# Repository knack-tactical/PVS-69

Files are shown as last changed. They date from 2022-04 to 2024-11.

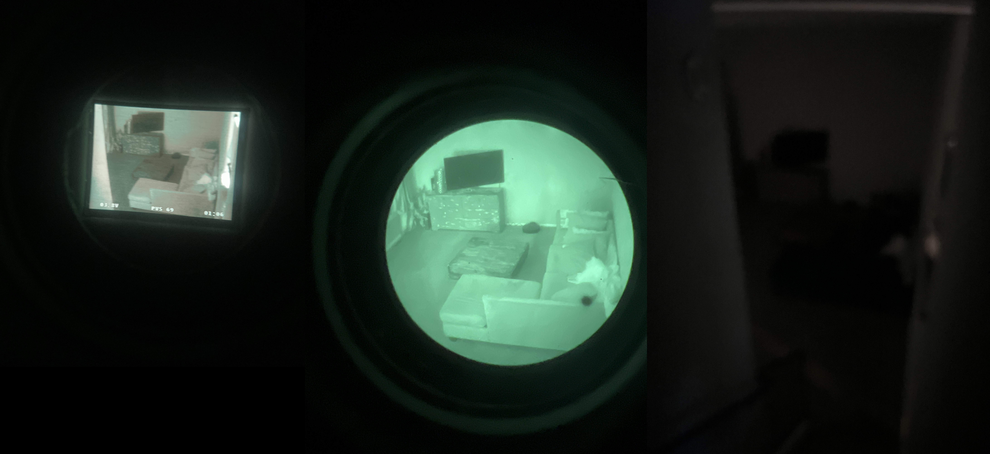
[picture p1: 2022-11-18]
.faq_pictures/cs_mount_digital.jpg

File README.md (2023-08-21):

# PVS-69

__Disclaimer__: This project is experimental, still in development, and is recommended for experienced tinkerers and solderers. Don't let that disuade you, but know that documentation, methods, and peocedures are not production ready.

[Frequently Asked Questions can be found here.](https://github.com/knack-69/PVS-69/wiki/Frequently-Asked-Questions)

### What is it?
PVS-69 is a FOSSCAD Night Vision Device (NVD). 
It uses a fpv drone camera and a small screen, rather than a IIT tube, and is designed to be mounted to a combat helmet.

### Why is it useful?
The current suggested components cost ~$500, about 10x less than the industry standard phosphor tube-based night vision.

### What is the current version?

The current version of the PVS-69 is the [Gen3 FOXTROT](https://github.com/knack-69/PVS-69/tree/main/Gen3%20FOXTROT). Housings for both V760 and V780 displays are available. The Gen3 FOXTROT also comes with a CS Mount Lens Adapter Assembly ([see here for writeup on lenses](https://github.com/knack-69/PVS-69/wiki/Current-Lens-Comparison)), which is interchangable with the NE3 Stock Lens Cap.

## Table of Contents

[PVS-69/Gen3 FOXTROT](https://github.com/knack-69/PVS-69/tree/main/Gen3%20FOXTROT) is the current version of the PVS-69 that is compatible with the V760A family of displays.

[PVS-69/Wiring Diagrams](https://github.com/knack-69/PVS-69/tree/main/Gen3%20FOXTROT/Wiring%20Diagrams) contains the current wiring diagrams for the current version of the PVS-69.

[PVS-69/_Older Versions/__Archive](https://github.com/knack-tactical/PVS-69/tree/main/Older%20Versions/__Archive) contains all the older versions of the PVS-69.

[PVS-69/Gen4 ALPHA](https://github.com/knack-69/PVS-69/tree/main/Gen4%20ALPHA) is an analog/'digital IIT' NVG housing, and is still in closed beta.

[PVS-69/_Olders Versions/__Archive/VPNVG](https://github.com/knack-69/PVS-69/tree/main/_Older%20Versions/__Archive/VPNVG)  is the PVS-69 Gen1 pano version using the adafruit displays. The VBNVG was a binocular version which was made in tandem with the VPNVG.

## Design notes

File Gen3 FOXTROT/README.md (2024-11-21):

# PVS-69 Gen3 FOXTROT

## Changes from ECHO to FOXTROT

The PVS-69 Gen3 FOXTROT is currently in beta testing. Take that as a word of caution. Please read all the changes.

(Beta testing) FOXTROT changes:
Expanded inner bore for use with V780 display.

Condensed overall pod length but moved the display bore deeper in the pod.

Opened up the area where the cam connector goes to accommodate more cams.

Added area for the OSD cable to come out the front.

Added CS mount quick change system. Still usable with the classic caps (Called 'NE3 Stock Sensor Cap' in .step)

Added holes to screw the sensor down for the lens quick change system.

New Gen4 Bridge (front load) does not require brass tubing however, should be able to accept it.

Both bridges now support the use of M3 bolts to individually adjust pod tightness.

Both bridges have a push-to overcome-latch to stow the tubes to the side.

Battery bridge has been slimmed down slightly more to accomadate narrower IPD, might need some tweaking.

As for the CS Mount Lens deal, basically, you can either use the NE3 Stock Lens (or XENOCAM Varifocus lens) *or* you can use the CS Mount Lens with the 'CS Mount Lens Assembly' (in the .step). [See this wiki page for links to the different lenses.](https://github.com/knack-69/PVS-69/wiki/Current-Lens-Comparison). If you aren't planning on using the CS mount lens, don't print the 'CS Mount Lens Assembly' items. ezpz

## Bill of Materials 

### This design requires the following printed components: 

1x [Dovetail](https://github.com/knack-69/PVS-69/blob/main/Gen3%20FOXTROT/STL/FOXTROT%20Gen4%20Dovetail.stl)

1x Bridge Body. In this design, there are 3 Bridge options:
1. Gen3 Bridge is the same bridge as older versions, with an internal battery compartment.
2. [Gen4 Bridge](https://github.com/knack-69/PVS-69/blob/main/Gen3%20FOXTROT/STL/FOXTROT%20Gen4%20Bridge%20Body.stl) is a newer, sleeker bridge that does *not* have an internal battery compartment. This version allows the user to more easily build the internals of the bridge and then load it into the front.

1x Bridge Backplate, which will depend on the Bridge body you choose

2x Sensor Caps - This will depend on whether you're using stock, CS Mount, M16, or some other lenses.

2x [TIPs (Tube Interface Pieces)](https://github.com/knack-69/PVS-69/blob/main/Gen3%20FOXTROT/STL/FOXTROT%20Brassless%20TIP.stl)

2x Ambi Tubes

- If you're using V760 Displays, [click here](https://github.com/knack-69/PVS-69/tree/main/Gen3%20FOXTROT/STL/Files%20for%20V760%20Displays)
- If you're using V780 Displays, [click here](https://github.com/knack-69/PVS-69/tree/main/Gen3%20FOXTROT/STL/Files%20for%20V780%20Displays)

1x Battery Cap (Only needed if using Gen3 Bridge)

2x Collars

- see 'Ambi Tubes' above

### This design requires the following physical components: (*This list is still under development*)

#### Hardware parts kits can be found at [vonscherfarms.com](https://vonscherfarms.com/).

---

#### Gen3 Bridge (Internal and External Battery)

1x [3-Position Rotary Switch](https://amzn.to/3TspGUS)

11x [M5x8 Bolts](https://amzn.to/3EyraZz)

11x [M5x5.8 Heat-set Inserts](https://amzn.to/3E0fzRt)

2x [RunCam Night Eagle 3](https://amzn.to/3Epdyhh)

2x V760A-5 or V760A-3 displays. These can be found on Ebay or AliExpress, expect a month for shipping.

1x [5.5x2.1mm DC Female Jack](https://amzn.to/3KLofNA)

1x [AA Spring Terminal](https://amzn.to/3EysOdH)

1x [Buck Converter](https://amzn.to/3KSzHHf) (if not using a [5V USB Power Bank](https://a.co/d/cTgl3xK), see [this writeup](https://github.com/knack-69/PVS-69/blob/main/Choosing%20the%20Right%20Battery%20Setup%20for%20My%20PVS-69.pdf) for more information)

2x [10x2mm Nitrile O-ring](https://amzn.to/37mEOko)

2x [13x3mm Nitrile O-ring](https://amzn.to/3KRAmsA)

5x [22x2mm Nitrile O-ring](https://amzn.to/3rrIp7N) (you can buy a [multipack](https://www.amazon.com/gp/product/B092MDGM110) that has all three sizes, thickness is not terribly important)

Approximately 24" of [20-24 AWG wire](https://amzn.to/3EoQ5yn)

3” section of 16AWG single strand wire (for internal battery positive connection)

---

#### Gen4 Bridge (External Battery Only)  

1x [Buck Converter](https://amzn.to/3KSzHHf) (if not using a 5V USB Power Bank, like [this one](https://a.co/d/cTgl3xK), see [this writeup](https://github.com/knack-69/PVS-69/blob/main/Choosing%20the%20Right%20Battery%20Setup%20for%20My%20PVS-69.pdf) for more information)

8x [M5x8mm Bolts](https://amzn.to/3EyraZz)

8x [M5x5.8mm Threaded Inserts](https://amzn.to/3E0fzRt)

6x [M3x45mm Bolts](https://a.co/d/08iu33J)

6x M3 Nuts (nylock would be better, but standard is fine)

1x [Push Button](https://amzn.to/3Txgdvg) or [3-Position Rotary Switch](https://amzn.to/3TspGUS)

4x [Brass Washers](https://amzn.to/3WSWOI2)

1x [5.5x2.1mm DC Female Jack](https://amzn.to/3KLofNA)

2x [12mm Nitrile O-ring](https://amzn.to/3fV4qcD)

3X [22mm Nitrile O-ring](https://amzn.to/3V5NT4D)

2x [35mm Nitrile O-ring](https://amzn.to/3fVgjz8)

Approximately 24" of [20-24 AWG wire](https://amzn.to/3EoQ5yn)

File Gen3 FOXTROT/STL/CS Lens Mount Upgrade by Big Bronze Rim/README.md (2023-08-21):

These files are an upgrade to the CS Lens Mount files for the Gen3 FOXTROT.
 - CS_Focus_Insert
    - This slots into the camera hole of the Gen3 FOXTROT Ambi Tube.
 - CS_Ribbed_Spacer
    - This is functionally the same as the CS_Lens_Mount_Adapter.stl, but is ribbed for aesthetics.
 - CS_Tapered_Retaining_Collar
    - This uses a screw to affix it to the lens so that it rotates when the lens body is spun to allow it to engage against the CS_Focus_Insert.
    - It uses the CS_Lens_Mount_Retainer, which just needs to be loosened to change the focus.
 - PVS14_Focus_Ring_Outer
    - This acts the same as the CS_Lens_Mount_Shroud.stl, but is a bit larger.

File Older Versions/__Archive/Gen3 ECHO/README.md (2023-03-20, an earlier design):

# PVS-69 Gen3 ECHO

## Changes from DELTA to ECHO

The PVS-69 ECHO has a few changes in functionality, size, and printabilty.

ECHO has improved water resistance with the addition of a retaining collar for the displays.

The bridge has been slimmed down and optimized for printing, now called Gen4 Bridge. The Gen4 Bridge has two variations, front-loading and back-loading. The back-loading version should help with wiring the internals of the bridge.

The internal battery connection for the Gen3 Bridge has been redesigned for a more reliable connection. O-ring lands in the tubes were removed in anticipation for a quick detach PCB contact system (still in progress). The tubes are optimized to be printed vertically with threads up. No supports should be needed!

## Bill of Materials

### This design requires the following printed components: 

1x [Dovetail](https://github.com/knack-69/PVS-69/blob/main/Gen3%20ECHO/STL/Dovetail.stl)

1x Bridge Body. In this design, there are 3 Bridge options:
1. [Gen3 Bridge](https://github.com/knack-69/PVS-69/blob/main/Gen3%20ECHO/STL/Gen3%20bridge%20body.stl) is the same bridge as older versions, with an internal battery compartment.
2. [Gen4 Bridge Front-Load](https://github.com/knack-69/PVS-69/blob/main/Gen3%20ECHO/STL/Gen4%20bridge%20front-load%20body.stl) is a newer, sleeker bridge that does *not* have an internal battery compartment. The front-loading version allows the user to more easily build the internals of the bridge and then load it into the front (away from your face).
3. [Gen4 Bridge Back-Load](https://github.com/knack-69/PVS-69/blob/main/Gen3%20ECHO/STL/Gen4%20bridge%20back-load%20body.stl) is the same as above, except it is accessed from the back (towards your face).

1x Bridge Backplate, which will depend on the Bridge body you choose

2x [Sensor Caps](https://github.com/knack-69/PVS-69/blob/main/Gen3%20ECHO/STL/RunCam%20sensor%20cap.stl)

2x TIPs (Tube Interface Pieces) - please note there are [+0°](https://github.com/knack-69/PVS-69/blob/main/Gen3%20ECHO/STL/%2B0%20TIP.stl) and [+2°](https://github.com/knack-69/PVS-69/tree/main/Gen3%20ECHO/STL) versions. 
    The +2° version gives a wider FOV

2x [Ambi Tubes](https://github.com/knack-69/PVS-69/blob/main/Gen3%20ECHO/STL/Ambi%20tube%20-%20ECHO%20.stl)

1x [Battery Cap](https://github.com/knack-69/PVS-69/blob/main/Gen3%20ECHO/STL/Battery%20cap.stl) (Only needed if using Gen3 Bridge)

2x [Collars](https://github.com/knack-69/PVS-69/blob/main/Gen3%20ECHO/STL/Collar.stl)

### This design requires the following physical components: (*This list is still under development*)

---

#### Gen3 Bridge (Internal and External Battery)

1x [3-Position Rotary Switch](https://amzn.to/3TspGUS).

11x [M5x8 Bolts](https://amzn.to/3EyraZz)

11x [M5x5.8 Heat-set Inserts](https://amzn.to/3E0fzRt)

2x [RunCam Night Eagle 3](https://amzn.to/3Epdyhh)

2x V760A-5 or V760A-3 displays. These can be found on Ebay or AliExpress, expect a month for shipping.

1x [300x8mm OD of Brass Tubing](https://amzn.to/3E3g5Oq) (you will only use 100mm to make 2x 45-46mm lengths)

1x [5.5x2.1mm DC Female Jack](https://amzn.to/3KLofNA)

1x [AA Spring Terminal](https://amzn.to/3EysOdH)

1x [Buck Converter](https://amzn.to/3KSzHHf) (if not using a [5V USB Power Bank](https://www.amazon.com/gp/product/B07QXV6N1B/), see [this writeup]() for more information)

2x [10x2mm Nitrile O-ring](https://amzn.to/37mEOko)

2x [13x3mm Nitrile O-ring](https://amzn.to/3KRAmsA)

5x [22x2mm Nitrile O-ring](https://amzn.to/3rrIp7N) (you can buy a [multipack](https://www.amazon.com/gp/product/B092MDGM110) that has all three sizes, thickness is not terribly important)

1X [2x8mm rare earth magnet](https://amzn.to/3Ostkga)

Approximately 24" of [20-24 AWG wire](https://amzn.to/3EoQ5yn)

3” section of 16AWG single strand wire (for internal battery positive connection)

---

#### Gen4 Bridge (External Battery Only)  

1x [Buck Converter](https://amzn.to/3KSzHHf) (if not using a 5V USB Power Bank, like [this one](https://www.amazon.com/gp/product/B07QXV6N1B/), see [this writeup](https://github.com/knack-69/PVS-69/blob/main/Choosing%20the%20Right%20Battery%20Setup%20for%20My%20PVS-69.pdf) for more information)

11x [M5x8 Bolts](https://amzn.to/3EyraZz)

11x [M5x5.8 Threaded Inserts](https://amzn.to/3E0fzRt)

1x [Push Button](https://amzn.to/3Txgdvg)

4x [Brass Washers](https://amzn.to/3WSWOI2)

1x [5.5x2.1mm DC Female Jack](https://amzn.to/3KLofNA)

2x [12mm Nitrile O-ring](https://amzn.to/3fV4qcD)

3X [22mm Nitrile O-ring](https://amzn.to/3V5NT4D)

2x [35mm Nitrile O-ring](https://amzn.to/3fVgjz8)

2x [45-46mm section of brass tubing](https://amzn.to/3E3g5Oq)

1x US nickel or other 19mm coin

Approximately 24" of [20-24 AWG wire](https://amzn.to/3EoQ5yn)

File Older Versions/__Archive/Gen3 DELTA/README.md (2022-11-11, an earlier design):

# PVS-69 Gen3 DELTA

### This design requires the following printed components: 

1x Dovetail

1x Bridge

2x Sensor caps (foxeer or runcam)

2x TIP (Tube Intergace Piece) - please note there are +0° and +2° versions. 
    The +2° version gives a wider FOV

1x left tube

1x right DVR tube or another left tube 

1x Battery cover

1x Backplate

### For physical components you will need the following

11x M5x7 heat set insert

11x M5x8 bolts. (for the dovetail, a button head screw is reccomend) 

2x Starlight FPV cameras. RunCam Night Eagle 3 or Foxeer Cat 3 work in this design. RunCam NE3 is suggested.

2x V760A-5 or V760A-3 displays. These can be found on Ebay or AliExpress, expect a month for shipping

1x 3-position rotary switch. I use "Rotary Switch 16MM Selector Switch 3 Position Select Switch"
this can be found on Amazon sold in a 2 pack

1x 300x8mm OD of brass tubing. you will only use 100mm

1x 5.5x2.1mm DC female jack. This can also be found on Amazon. I used the plastic ones sold in a 5 pack

1x AA battery terminals. these are sold in a 20 pack

1x Buck Converter. I used the eBoot Mini MP1584EN DC-DC Buck Converter Adjustable Power Supply Module (6 Pack) 

2x 10x2mm Nitrile Oring

2x 13x3mm Nitrile Oring

5x 22x2mm Nitrile Oring (you can buy a multipack that has all three sizes)

1x 2x8mm rare earth magnet

You will also need aproximately 24" of 20-24 AWG wire, we recommend black and red. 

### Optional Components

If you would like to try for the auto shutoff function you will need 

6x Rare earth magnets 2mmx8mm diameter

2x .5A reed switches. 

2x 2N7000 mosfets. 

1x custom PCB. this can be bought from myself or ordered from PCBWAY. 
It is not "needed" but I HIGHLY HIGHLY reccomend it!

2x 10k resistor

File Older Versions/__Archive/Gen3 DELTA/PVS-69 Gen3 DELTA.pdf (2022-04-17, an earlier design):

PVS-69 GEN3 Delta.

this design requires the following printed components:

1X Dovetail

1X Bridge

2X Sensor caps (foxeer or runcam)please note there are +0 and +2.
I prefer using the +2 as it wides fov and gives me a better view of the tube.

1X right tube

1X left tube or a DVR tube.

1X Battery cover

1X Backplate.

For physical components, you will need the following. However please keep in mind you can buy the kit from my website containing all the hardware pieces except from the display and the cameras. It will definitely save you some money too!

11X M5x7 heat-set insert
https://amzn.to/3KTgOUw

11X M5x8 bolts. (for the dovetail a button head is recommended) https://amzn.to/3jIG6Ja

2X starlight FPV cameras. runcam or foxeer work in this design.
https://amzn.to/3Epdyhh
https://amzn.to/3KSAuYJ

2X V760A-5 or V760A-3 displays. these can be found on eBay, expect a month for shipping. (Optionally there is now the V780A and the V770A) these have the same bodies but a better ocular lens I have not yet been able to test them

1X 3 position rotary switch. I use "Rotary Switch 16MM Selector Switch 3 Position Select Switch"
this can be found on amazon sold in a 2 pack
https://amzn.to/38KcJUv

1X 300x8mm OD of brass tubing. you will only use 100mm
https://amzn.to/3xuOuE7

1X 5.5x2.1mm DC female jack. this can also be found on amazon. I used the plastic one they are sold in a 5 pack
https://amzn.to/3KLofNA

1X AA battery terminals. these are sold in a 20 pack
https://amzn.to/3KSQGZZ

1X buck converter. I used the eBoot Mini MP1584EN DC-DC Buck Converter Adjustable Power Supply Module (6 Pack)
https://amzn.to/3KSzHHf

2X 10mmx2mm Nitrile Oring https://amzn.to/37mEOko

2X 13mmx3mm Nitrile Oring
https://amzn.to/3KRAmsA

5x 22x2mm Nitrile Oring (you can buy a multipack that has all three sizes) https://amzn.to/3rrIp7N

1X 2x8mm rare earth magnet
https://amzn.to/3Ostkga

you will also need approximately 24" of wire I recommend black and red 24 AWG.

OPTIONALLY

If you would like to try the auto-shutoff function you will need

6X Rare earth magnets 2mmx8mm diameter https://amzn.to/3Ostkga

2X .5A reed switches.
https://amzn.to/3rxym0O

2x 2N7000 mosfets.
https://amzn.to/3L2IyGg

1X custom PCB. this can be bought from me or ordered from PCBWAY. It is not "needed" but I HIGHLY HIGHLY recommend it!

2x 10k resistor
https://amzn.to/36jRiJ6

A video build guide for the auto-off is coming soon
for now please enjoy this write-up of the standard setup without using a custom PCB.

start by inerting heat-set inserts into all locations.
4 per tube and 3 on the bridge. set the dovetail insert deep enough that plastic forms over the top of it

next, cut your brass tube down and make 2X 45-46mm lengths. this will act as the hinge pin for the tubes.
clean up any burs inside the brass.
ensure the brass fits in the bridge and backplate and can turn somewhat freely.

with the brass, tubes pushed all the way into the bridge slide on 1 10x2mm oring for each side of the bridge.

slide the cover on behind the oring.
looking through the bottom of the cover mark the brass you can see through the cover hole. Disassemble and drill or cut out the brass tube where you marked.

To start assembling the bridge

Ensure the DC connector fits somewhat loosely in the hole on the right side of the bridge. You need to be able to turn this jack.

Slide the rubber cover over the jack wires and then insert the wires through the bridge. then thread the nut on.
hold the nut down and rotate the jack clockwise to tighten the nut. be careful not to tear the rubber cover.

next, disassemble the switch. from the back of the switch, you should see 6 terminals.
2 marked 'C" 2 marked "NO" and 2 marked "NC"
using side cutters snip off the "NC" terminals

Using a pick or some tweezers you can remove the female terminals from
the wiring harness that comes with the switch

for the purpose of this write up blue will be NO and green will be C.
slide the wires onto their respective terminals.
(I suggest soldering the terminals on and covering them with heat shrink tubing.)

install the metal ring and castle nut into the bridge and set them over the hole for the switch. thread the leads of your switch through the bridge ring and castle nut and using a pick or tweezers
turn the castle nut clockwise to tighten the switch into the bridge
(I find a 90-degree pick through the battery port works best.)

Now connect a 6" section of red wire to the positive "out" side on the buck.
solder the non-spring terminal to the red wire

now connect the positive and negative from the DC jack to the Buck on the "IN" side.

moving over to the common/green wires from the switch. cut one wire to be approximately 4 inches long.
Solder the spring side of the battery terminal to it.

solder the other green wire to the negative "out" side on the buck.

now connect the two blue/NO wires together and do a T Joint with 16-20 inches of black wire. run that out either side of the bridge this will go to the tubes.

next, take a 16-20 inch section of red wire and split the casing in the middle.
twist that up and solder it through to the positive "out" side on the buck.
thread the wire through the bridge and out to the tubes.

at this point ensure all bare wire is covered up and there is no risk of shorting anything. I wrapped my buck in electrical tape to be sure.
ensure everything will fit into the bridge without being too tight.

apply a small amount of glue to the cover where the brass tube will sit.
Insert the brass tube making sure the hole in the bottom of the cover aligns with the hole you cut in the tube.
on each brass tube/cover install a 10mm oring and a 13mm oring on the opposite end.

(if using the +2 covers ensure you do not mix up the left and right covers as they are not the same)

now thread the wire coming out of the bridge through the brass tube and out the bottom of the cover.

gently pulling on the wires to ensure it doesn't get caught in the bridge slide the brass tube into the bridge on each side.

Now you will need to connect a voltmeter to one of the leads coming from the bridge. turn the switch to the side that does not have the spring terminal for the internal battery. connect your battery source to the DC connector on the bridge.
(I do not yet have a Battery pack design completed but will soon)

you should be reading voltage when the switch is turned in the proper direction.
using a Phillips screwdriver adjust the potentiometer on the buck until your voltmeter reads approximately 4.8-5V.

Glue the spring terminal onto the backplate as close to the center of the circle as you can. and set the bridge aside.

Moving to the tube assembly you will repeat the following process on both tubes.

cut the wire coming off the display just before the first coil.
giving you approximately 5 inches of wire from the display.
using a razor carefully cut down the side of the black silicone casing about 1.5 to 2 inches.
you should see a red, white, black and green wire. strip these back about 1/2 inch
being careful not to tear the thin copper wire.

moving over to the runcam harness you should see a small pair of wires that are black and blue. DO NOT CUT THOSE.

there is another small JST connector with a red, black, and yellow wire. snip off the connector and strip the wires back.
there is a free-floating blue wire. strip that as well.

from the camera cable.
connect the red and blue wire to the red display wire. and T that connection with a 4" red wire. connect the black from the camera to the black and white wires from the display and T that with a 4" black wire.

finally, connect the yellow to green

now without soldering twist the red and black from the bridge directly to the harness you just made.
connect the camera and OSD keypad and power the system on.
The screen should flash blue and then power on and show the camera image.

The following settings are what I change on the night eagle.

change "day-night" to B&W.
turn AGC to the maximum.
in "system" change to PAL
the setting WDR is defaulted to LOW.
(turning this up can help the gain for NV but cause motion blur)
in system you can change the "RUNCAM" to a custom setting I do "PVS 69"

I do not have any recommended settings for the foxeers yet I will soon.

once you've made your settings changes you can unplug the OSD and camera.
insert the harness through the back of the tube running the two RED and Black T wires out the top and the camera connector through the slot in the front. at this point, you can decide if you want to have the OSD keypad externally mounted. if so drill a small hole in the flat area near the front of the tube allowing the OSD cable to fit through.

plug your camera into the connector and carefully feed any excess cable back into the tube so as not to get caught behind the cameras.

slide your display into the tube the two holes on the top of the display will align with the two holes on the tube. it is a very snug fit and should not require glue.
insert the two M3 screws that came with your display.

for the sensor cap
use the edge of a chisel o scrape away small amounts of the inside circle allowing the lens to fit snugly into the cap. before finally installing the cap install the 22x2mm oring on the threads of the tube.
make sure you focus your camera and set the lock ring in place before installing the cap.

once the camera is focused back it out 3 to 4 turns and install the cap. the cap should turn the camera lens back into focus. you may need to repeat this several times to get it perfect. now you can install the orings in the ring land at the mounting portion of the tubes and on the threads of the bridge.
connect and solder your leads coming from the tube to the leads from the bridge and push any excess into the tube. don't trim it in case you have to come back later.
bolt the tube to the bridge and you should be set.

put the rare earth magnet on the non-spring battery terminal. This will hold the terminal to the battery securely. 18650 has been hit or miss for me so I recommend using 2x CR123s.

install the backplate ensuring you don't pinch any wires. It's a tight fit!
one the backplate is in place tighten the two screws securing it.

next, install the dovetail to the top of the bridge. if the head of your bolt is too high for the mount you may need to grind it down or use a button head. I set my dovetail as far back as it will go to clear my glasses.

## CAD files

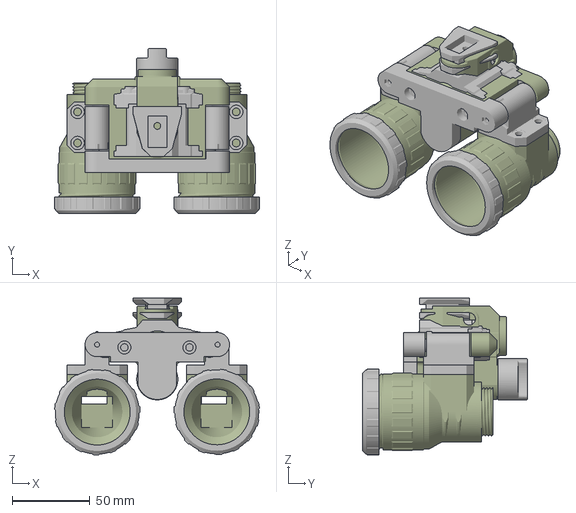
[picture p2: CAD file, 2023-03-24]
Gen3 FOXTROT/3MF/PVS-69 Gen3 FOXTROT_V760/PVS-69 Gen3 FOXTROT_V760 - No Lens Cap.3mf
131.8 x 105.9 x 100.9 mm

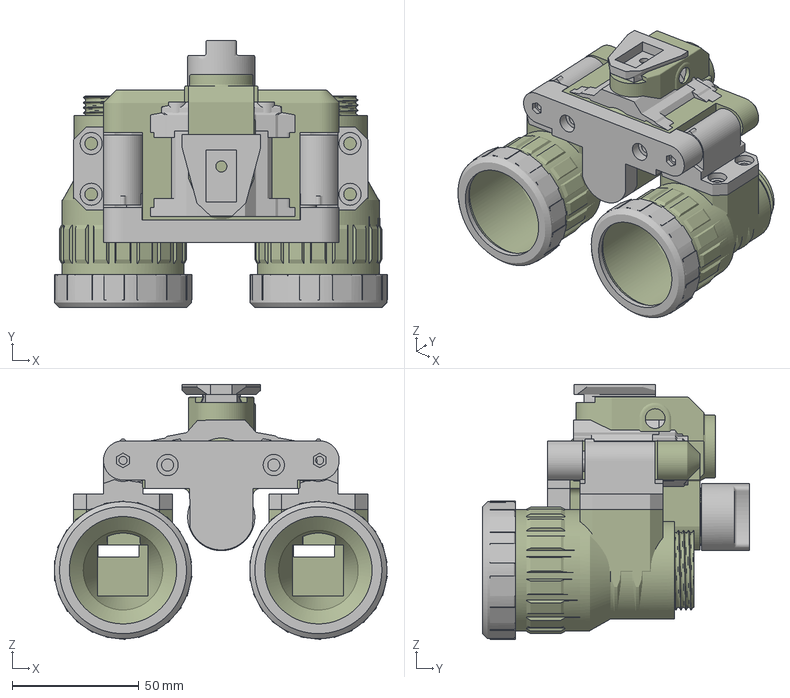
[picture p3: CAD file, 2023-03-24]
Gen3 FOXTROT/3MF/PVS-69 Gen3 FOXTROT_V780/PVS-69 Gen3 FOXTROT_V780 - No Lens Cap.3mf
131.2 x 105.4 x 100.5 mm

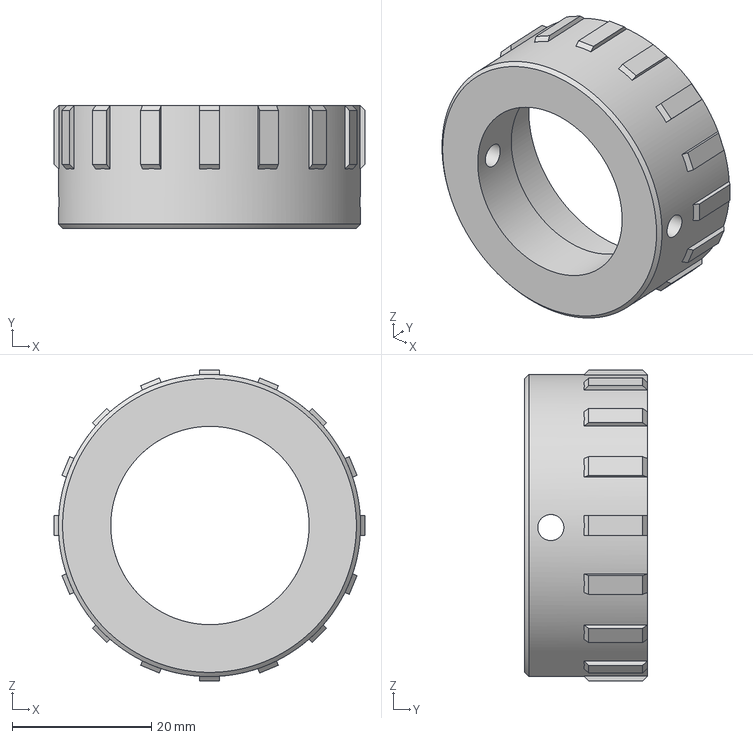
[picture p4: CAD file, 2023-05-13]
Gen3 FOXTROT/STL/CS Lens Mount Upgrade by Big Bronze Rim/PVS14_Focus_Ring_Outer.3mf
44.7 x 17.7 x 44.7 mm

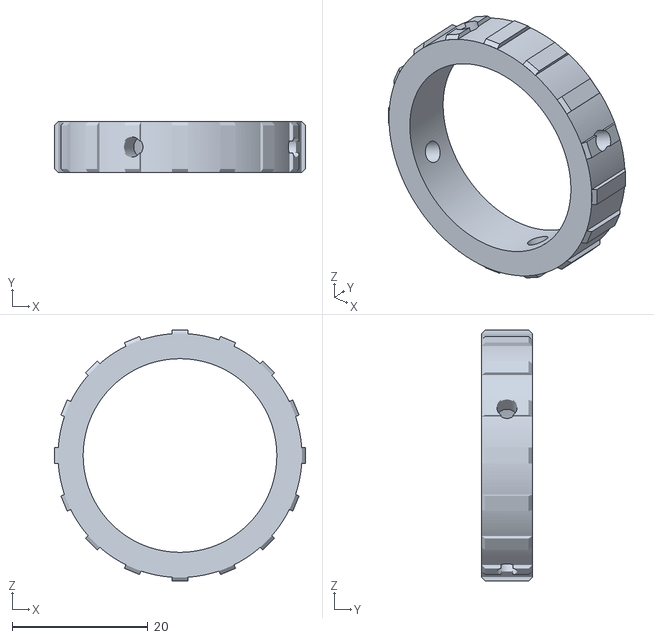
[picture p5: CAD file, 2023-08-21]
Gen3 FOXTROT/STL/CS Lens Mount/CS_Lens_Mount_Shroud.stl
36.9 x 7.54 x 36.9

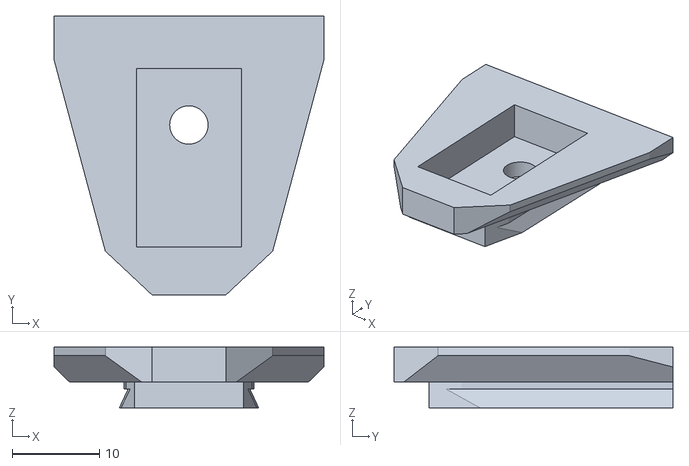
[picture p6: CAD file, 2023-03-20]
Gen3 FOXTROT/STL/FOXTROT Gen4 Dovetail.stl
31.0 x 32.0 x 7.00

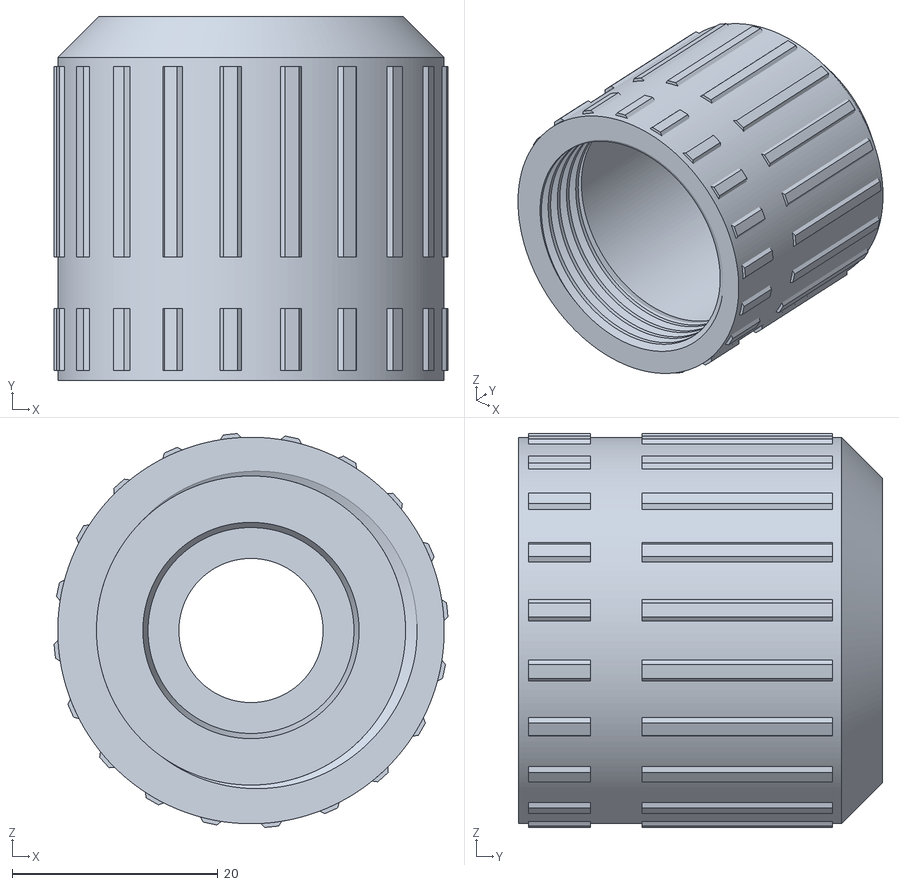
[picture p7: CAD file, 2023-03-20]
Gen3 FOXTROT/STL/M12 and M16 Lens Adapters and Caps/Foxtrot_M16_Cap_by_KNACK.stl
38.3 x 35.4 x 38.3

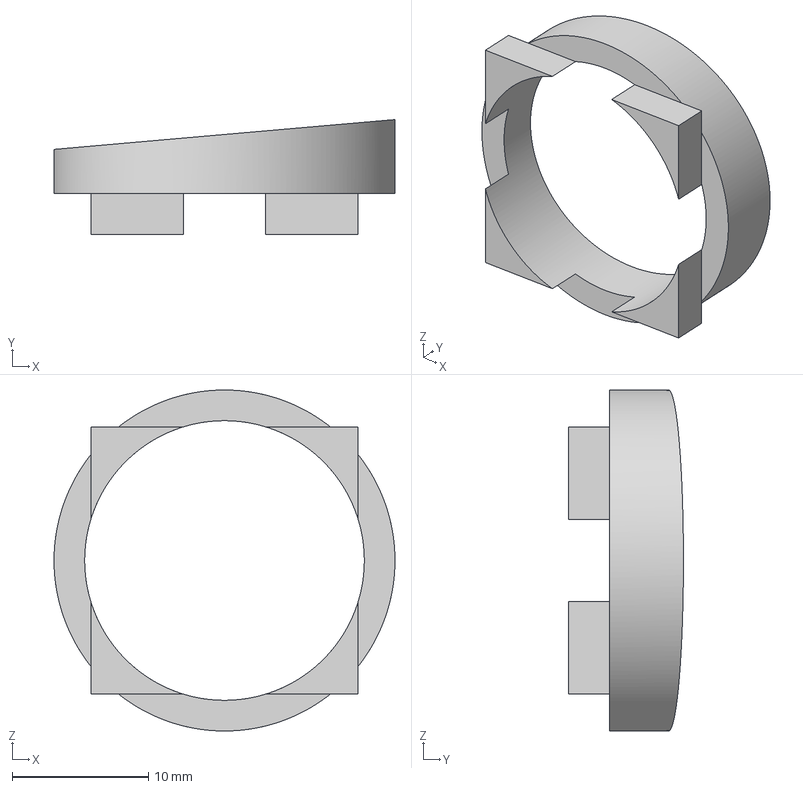
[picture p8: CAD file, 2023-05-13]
Gen3 FOXTROT/STL/CS Lens Mount Upgrade by Big Bronze Rim/CS_Focus_Insert.3mf
25.0 x 8.42 x 25.0 mm

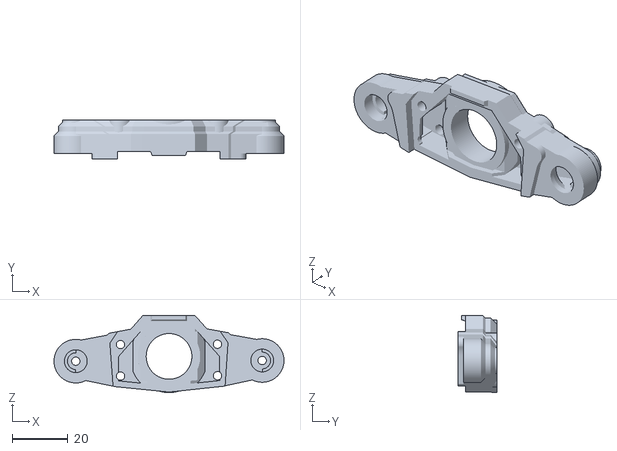
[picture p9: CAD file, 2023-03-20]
Gen3 FOXTROT/STL/FOXTROT Gen4 Bridge Frontplate.stl
82.6 x 13.8 x 27.7

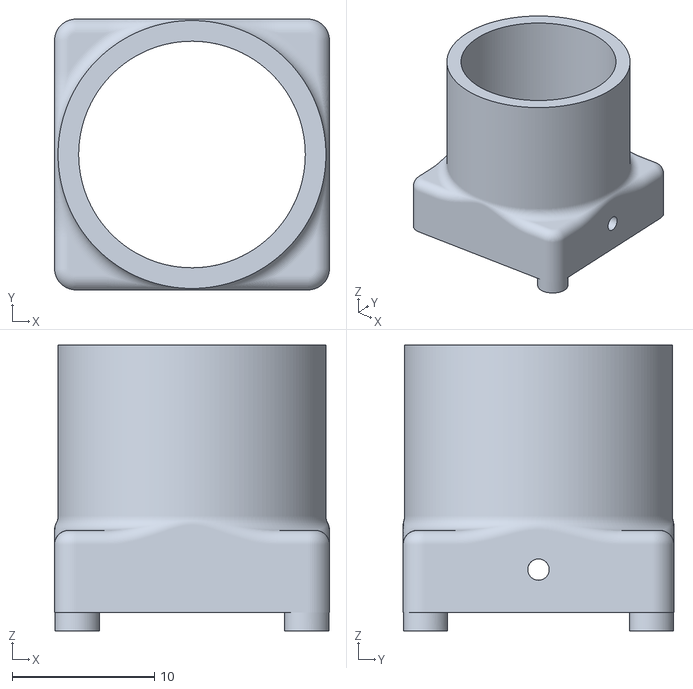
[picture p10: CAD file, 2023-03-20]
Gen3 FOXTROT/STL/M12 and M16 Lens Adapters and Caps/Starlight_Adaptor.stl
19.3 x 19.0 x 20.0

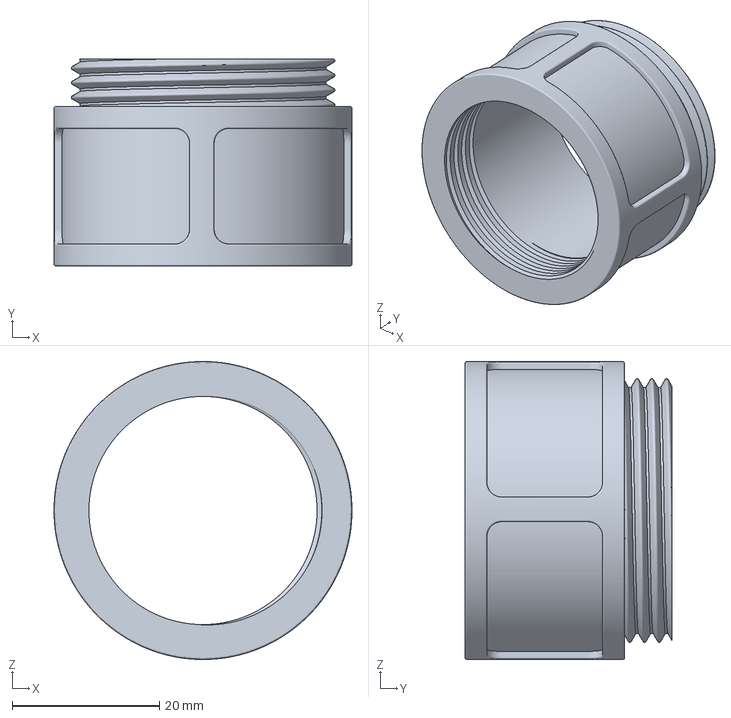
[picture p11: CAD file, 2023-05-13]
Gen3 FOXTROT/STL/CS Lens Mount Upgrade by Big Bronze Rim/CS_Ribbed_Spacer.3mf
40.5 x 28.2 x 40.5 mm

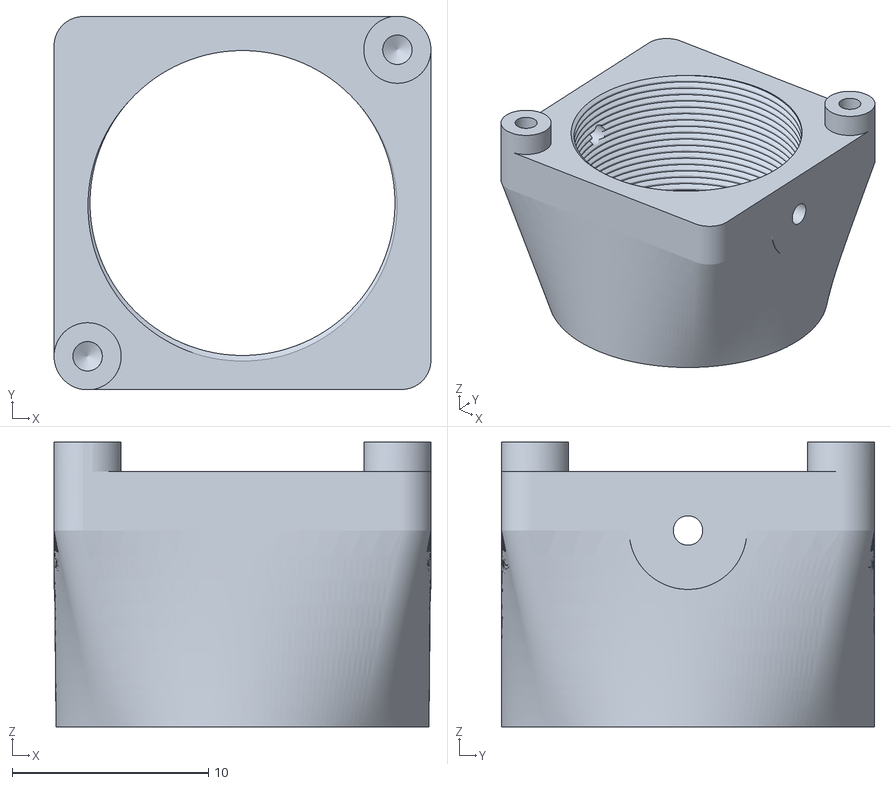
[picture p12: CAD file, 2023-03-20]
Gen3 FOXTROT/STL/M12 and M16 Lens Adapters and Caps/Threaded_M16_Adaptor.stl
19.2 x 19.0 x 14.5

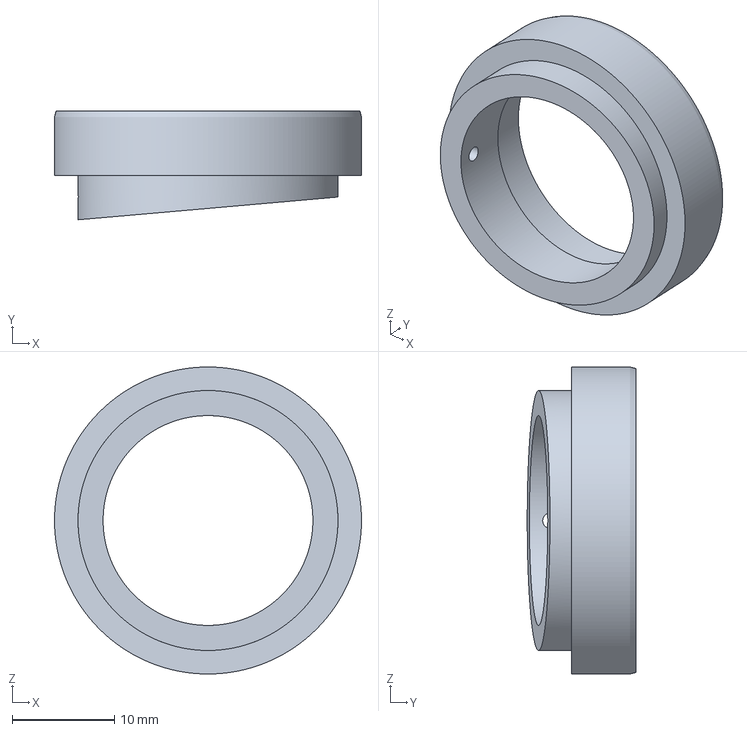
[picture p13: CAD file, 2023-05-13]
Gen3 FOXTROT/STL/CS Lens Mount Upgrade by Big Bronze Rim/CS_Tapered_Retaining_Collar.3mf
30.0 x 10.6 x 30.0 mm

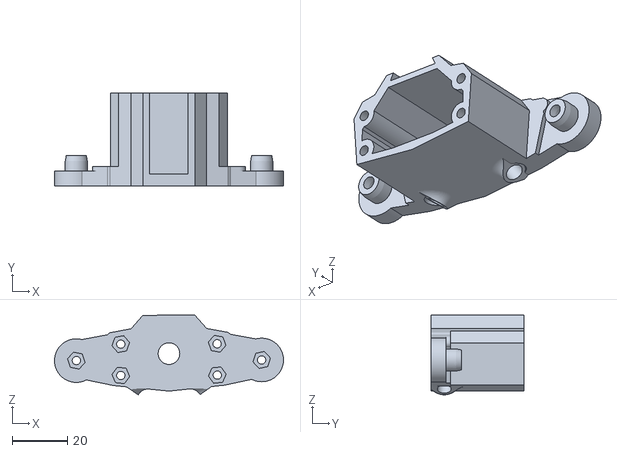
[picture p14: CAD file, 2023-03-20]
Gen3 FOXTROT/STL/FOXTROT Gen4 Bridge Body_NO_DOVETAIL_HEATSET.stl
82.7 x 33.7 x 28.8

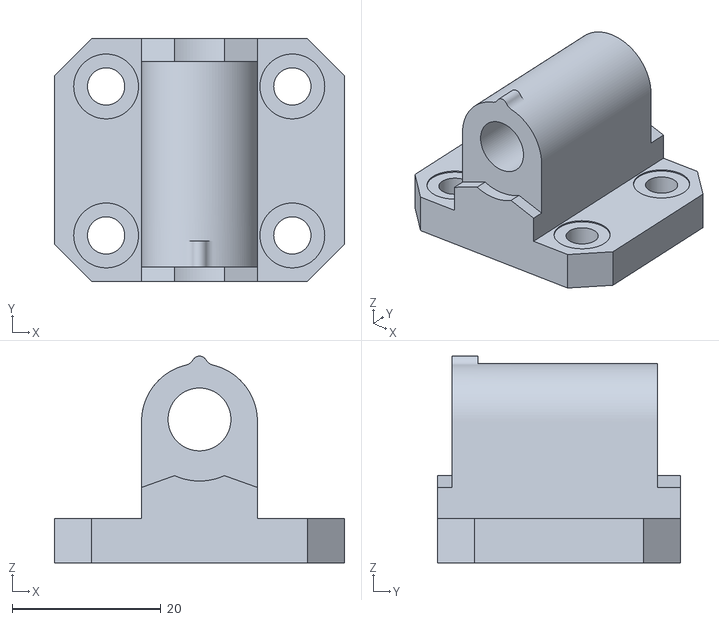
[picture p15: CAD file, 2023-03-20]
Gen3 FOXTROT/STL/FOXTROT Brassless TIP.stl
38.9 x 32.7 x 27.8

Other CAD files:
Gen3 FOXTROT/3MF/PVS-69 Gen3 FOXTROT_V780_Thicker Display Wall/PVS-69 Gen3 FOXTROT_V780_thicker display wall - No Lens.3mf
Gen3 FOXTROT/STL/FOXTROT Gen4 Bridge Body.stl
Gen3 FOXTROT/STL/FOXTROT Printable Washer.stl
Older Versions/__Archive/Gen3 CHARLIE/STL/+7 TIP_right.stl
Older Versions/__Archive/Gen3 CHARLIE/STL/+0 TIP.stl
Older Versions/__Archive/Gen3 CHARLIE/STL/+2 TIP_left.stl
Older Versions/__Archive/Gen3 CHARLIE/STL/+2 TIP_right.stl
Older Versions/__Archive/Gen3 CHARLIE/STL/+7 TIP_left.stl
Older Versions/__Archive/Gen3 CHARLIE/STL/Backplate.stl
Older Versions/__Archive/Gen3 CHARLIE/STL/Battery cover.stl
Older Versions/__Archive/Gen3 CHARLIE/STL/Bridge.stl
Older Versions/__Archive/Gen3 CHARLIE/STL/Collar.stl
Older Versions/__Archive/Gen3 CHARLIE/STL/Dovetail.stl
Older Versions/__Archive/Gen3 DELTA/.3MF/BatteryPack.3mf
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

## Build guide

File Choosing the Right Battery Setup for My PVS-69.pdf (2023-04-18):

# Choosing the Right Battery Setup for My PVS-69

There are currently three different battery configurations supported for the PVS-69 ECHO:

Internal and External Battery
External Battery with no Buck Regulator
External Battery with Buck Regulator

As of writing this, there is an 18650-based, 3D-printed battery pack in development, but it is not in an open beta yet. Keep an ear out for that.

Let's quickly define some terms. We will refer to the “higher voltage wire” as the wire with unregulated voltage (i.e., 6V from two CR123As or 7.4V from an 18650) after the switch. The “lower voltage wire” will be the regulated <5V after the Buck Regulator.

## Internal and External Battery Configuration

*A larger picture of the wiring diagram can be found here* (https://github.com/knack-69/PVS-69/blob/main/Wiring%20Diagrams/Internal_and_External_Batteries.png)
In order to include an internal battery, you must use the Gen3 Bridge design. (https://github.com/knack-69/PVS-69/blob/main/PVS-69%20versions/Gen3%20ECHO/STL/Gen3%20bridge%20body.stl) The slimmer Gen4 Bridge design does not have space for an internal battery. For the internal battery, you will probably want to use 2 CR123A batteries in series, giving a nominal 6V. Since this voltage is more than the screen can take
without burning out, you will need a
Buck Regulator to regulate the
voltage between 3V and 5V.

In this configuration, it is important to connect the incoming positive leads (from internal and external battery positives) to the “NO” pads of the 3-position rotary switch. The ‘out’ pad of the switch (in the sense that voltage is coming in from either battery and out to the tubes), should
be the “C” pads.

You may notice that the higher

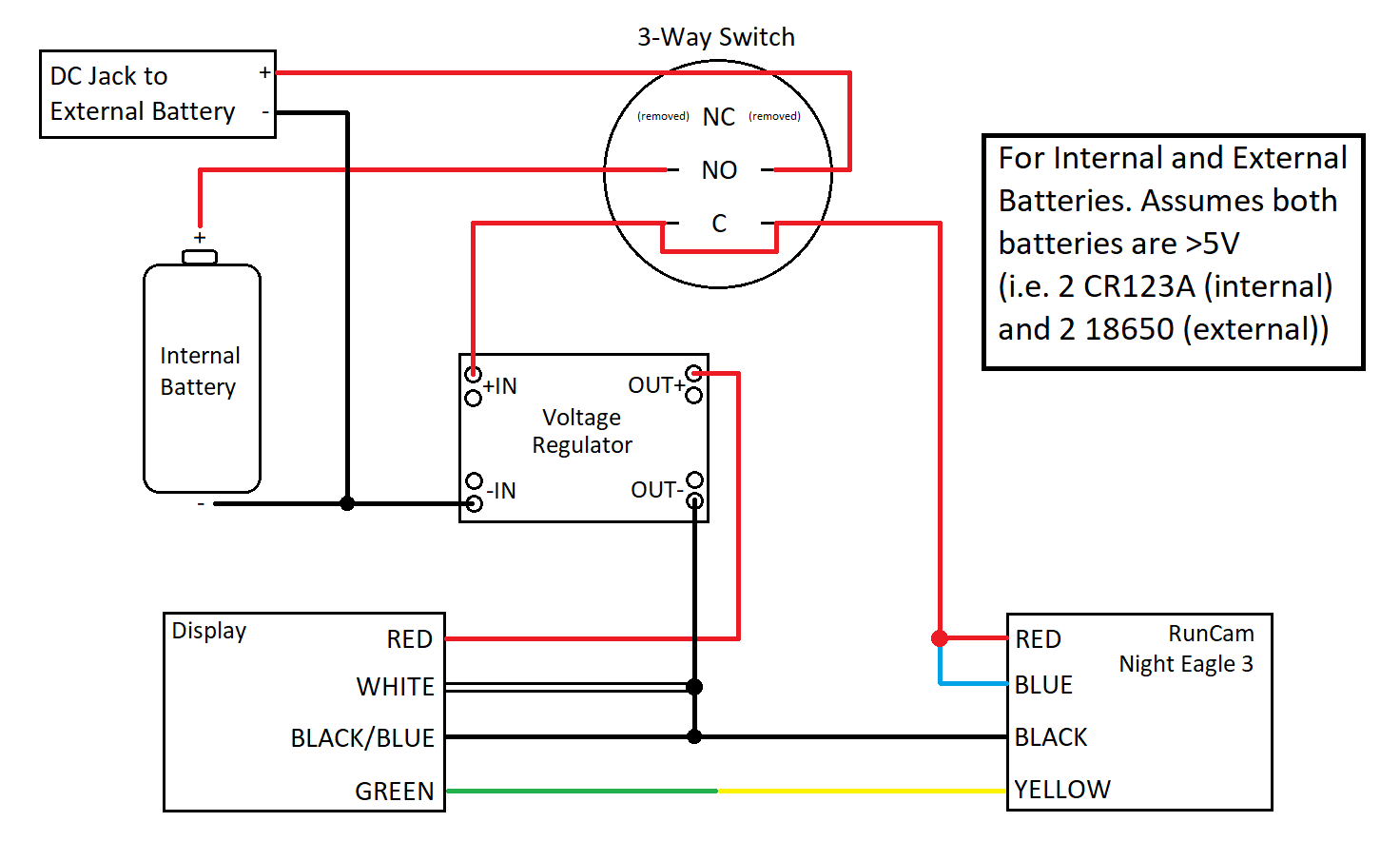
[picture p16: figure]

voltage wire is connected to the “C” pad which is connected to the “+IN” of the Buck Regulator. That means that you can put the higher voltage wire wherever you’d like between either of the “C” pads or the “+IN” pad, so long as the two “C” pads are connected. Just make sure you know which thing the higher voltage wire is going to, because if you accidentally solder it to the Display and power the system, you will fry the display.

## External Battery with no Buck Regulator Configuration

*A larger picture of the wiring diagram can be found here* (https://github.com/knack-69/PVS-69/blob/main/Wiring%20Diagrams/External_Battery_Only_NO_BUCK.png)
This configuration is the simplest to
understand and the simplest to implement.
No Buck Regulator, no fiddling with 18650s
or CR123As. This is the simple man’s configuration.

There is one caveat with this configuration and that is that there is no over-voltage protection for your displays (yet, we may have something in the works). But fear not! A simple 5V USB power bank (https://www.amazon.com/gp/product/B07QXV6N1B/) and a USB to 5.5x2.1mm cable (https://www.amazon.com/gp/product/B073SNC45F) is all you need. Of course, this method may lack water resistance, but
being out in the rain sucks anyways. Just
strap that bad boy to the back of your

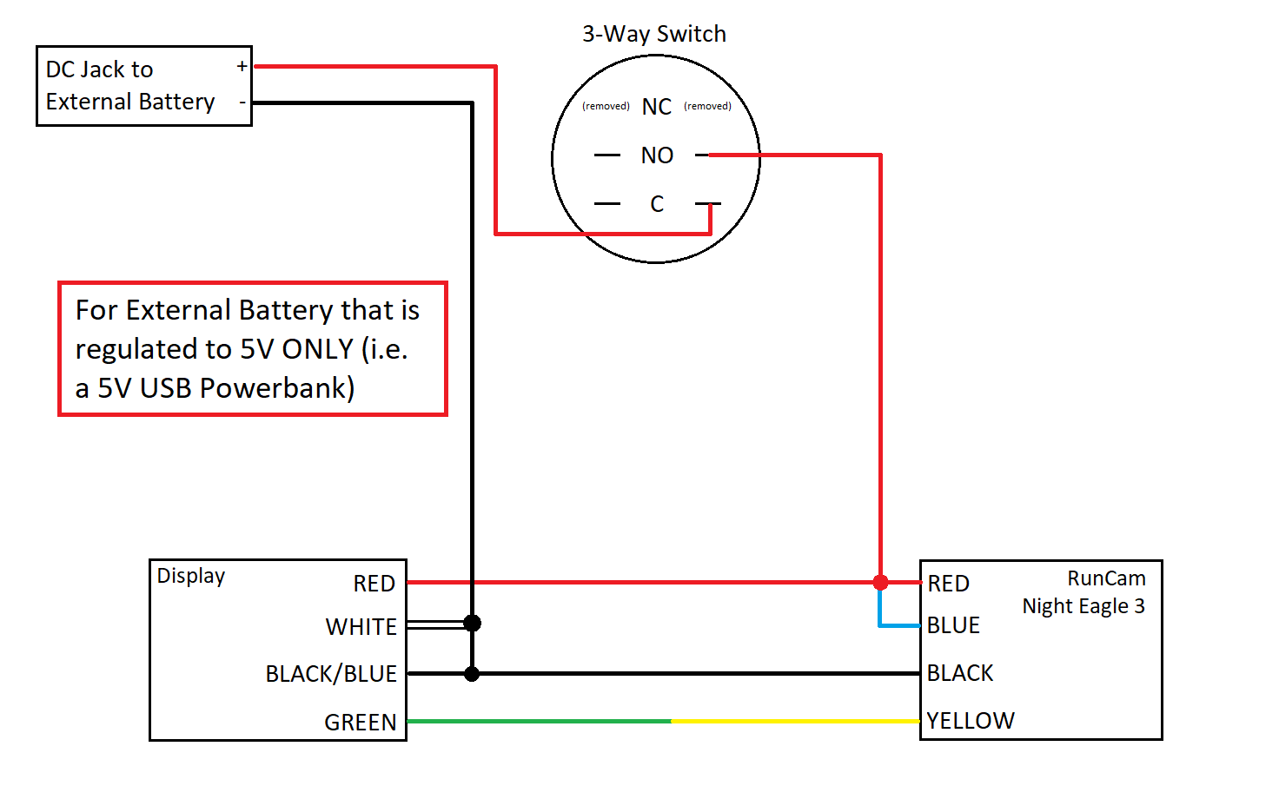
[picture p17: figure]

helmet, plug it into the external battery jack on either generation’s bridge, and you’re off to the races.

One note about the wiring diagram and the Gen4 Bridge design. The wiring diagram lists a 3-position rotary switch (3-Way Switch), but the Gen4 can use a latching push-button switch instead. The wiring diagram is exactly the same except that the switch only has two terminals instead of six. I’m sure you can figure it out.

## External Battery with Buck Regulator Configuration

*A larger picture of the wiring diagram can be found here* (https://github.com/knack-69/PVS-69/blob/main/Wiring%20Diagrams/External_Battery_Only_with_Buck.png)
This is exactly the same as the
Internal/External configuration, except
there is no internal battery, so go read
that and ignore anything about an internal battery. There are two notable exceptions, however. Instead of a 3-position rotary switch, you can use a latching push-button switch. Also, you can use either the Gen3 bridge or one of the Gen4 bridges.

## Final Thoughts

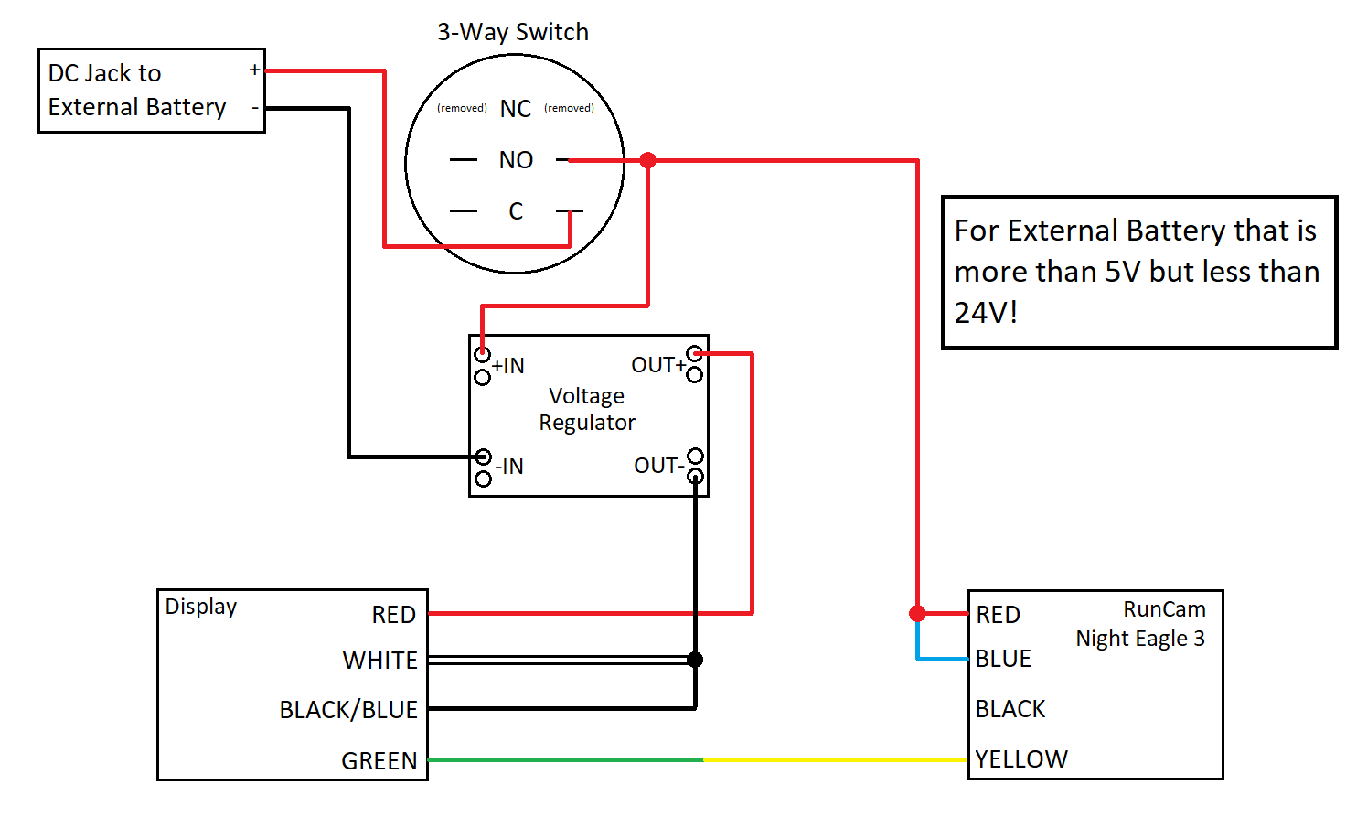
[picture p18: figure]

If you have any questions or think this document sucks, let us know in the #feedback channel of the discord. Say something like “Hey this ‘Choosing the Right Battery Setup’ document sucks and I hate it, even though someone put their heart and soul into it. Here is a very thorough and detailed list of improvements…”

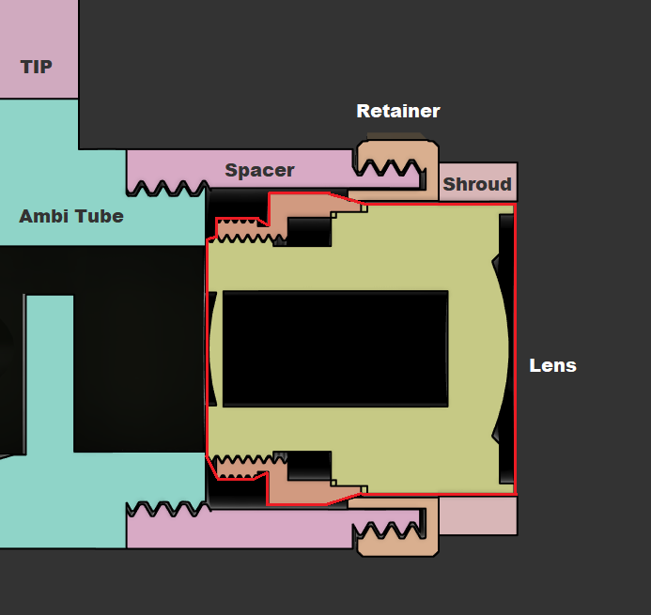
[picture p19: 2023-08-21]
Gen3 FOXTROT/STL/CS Lens Mount/Assembly Guide.png

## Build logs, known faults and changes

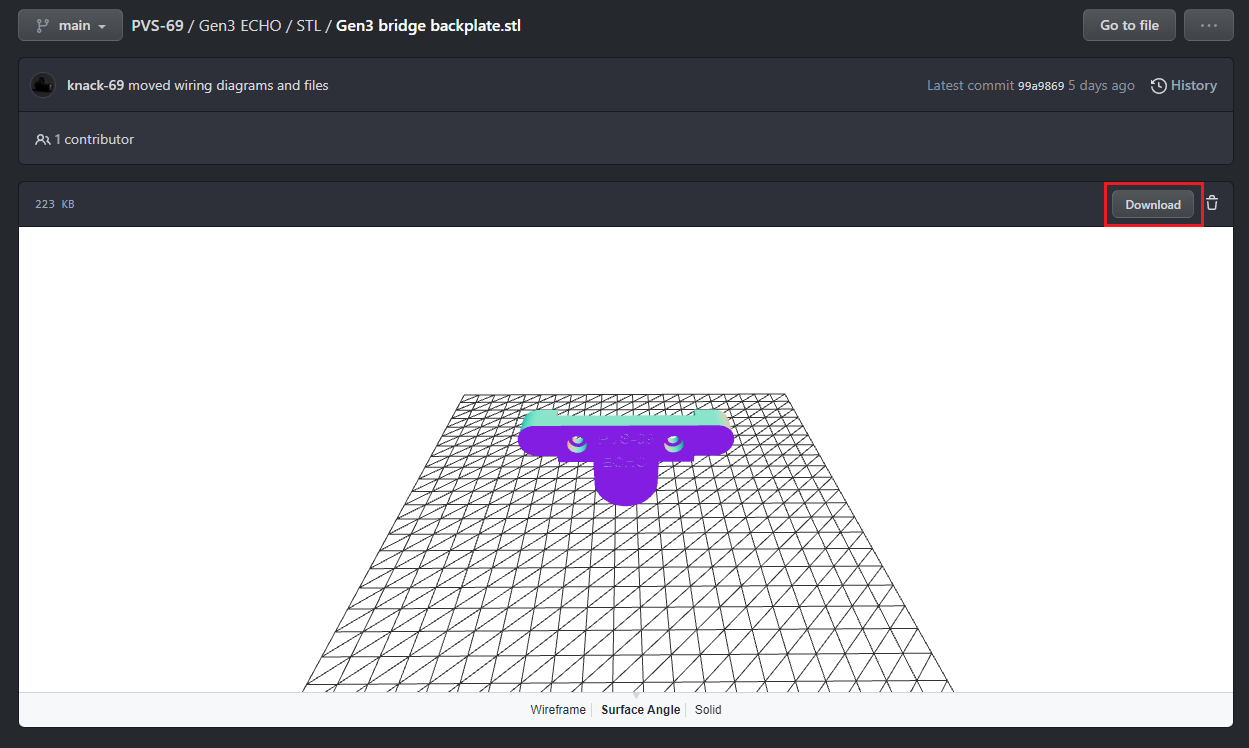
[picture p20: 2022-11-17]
.faq_pictures/download_single_file.png

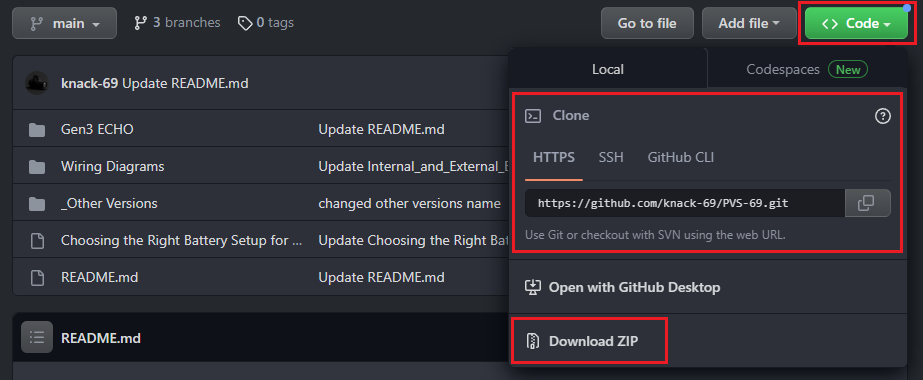
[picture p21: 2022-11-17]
.faq_pictures/downloading_files.png

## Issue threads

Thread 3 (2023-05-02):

Gen 4 backplate

GCUGrayArea, 2023-05-02:
I can't find the file for the Gen 4 bridge backplate, and it definitely doesn't look like the Gen 3 will fit. Is this omitted or did this become unnecessary on the Gen 4 with the battery compartment removed? The readme for the Foxtrot is not clear on this.

knack-tactical, 2023-05-02:
With the FOXTROT Gen4 bridge, there is the [bridge body](https://github.com/knack-tactical/PVS-69/blob/main/Gen3%20FOXTROT/STL/FOXTROT%20Gen4%20Bridge%20Body.stl) and the [frontplate](https://github.com/knack-tactical/PVS-69/blob/main/Gen3%20FOXTROT/STL/FOXTROT%20Gen4%20Bridge%20Frontplate.stl), which was switched to as it makes assembly easier compared to a backplate.

Closed 2023-05-02.

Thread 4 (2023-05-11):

Single tube bridge when?

AndreiX1308L, 2023-05-11:
Is there ever going to be a design for PVS-69 for only use with a single tube? I like this project very much but I'm broke and I can't afford to build a binocular set. So, is there a monocular variant of this? If yes, when will it be released?

Sorry for making an issue ticket. I couldn't find a way to just make it as a question.
(and also I'm sorry for my broken english. I'm not a native english speaker)

Closed 2023-07-06.

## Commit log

2022-03-30 added STEP, STL, Renders and initial files
    [Right Body (UPDATED).stl]
2022-04-17 Added STLs and STEPs for DELTA
    Added STEPs and STLs for Delta including Vaughns PCB design gerber files
    [+0right cover.stl, +2 Left cover.stl, +2 right cover.stl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]
2022-10-03 Create ECHO STL
2022-10-24 reorganized folder structure
    [+0right cover.stl, +2 Left cover.stl, +2 right cover.stl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]
2022-10-31 PVS-69 file upload
    [0 degree (2).stl, Ambi tube (1).stl, BAT BRIDGE.stl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]
2022-10-31 moved some stuff around
    [Ambi tube (1).stl]
2022-10-31 cleaned up step/f3d, made a few .3mf, renamed a bunch of stuff
    [+0 TIP.stl, +0right cover.stl, +2 Left cover.stl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]
2022-10-31 moved wiring diagrams
2022-11-11 updated BOM with links and variants
2022-11-11 updated gen4 buck link
2022-11-11 updated push button wordage
2022-11-11 added power jack for gen4
2022-11-12 updated wiring dirgrams
2022-11-12 renamed wiring diagrams
2022-11-12 Create Choosing the Right Battery Setup for My PVS-69.pdf
2022-11-12 Update Choosing the Right Battery Setup for My PVS-69.pdf
2022-11-12 moved wiring diagrams and files
    [+0 TIP.stl, +2 TIP_left.stl, +2 TIP_right.stl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]
2022-11-12 changed other versions name
    [+0 TIP.stl, +2 TIP_left.stl, +2 TIP_right.stl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]
2022-11-14 gen4 version were backwards
    [Gen4 bridge back-load body.stl, Gen4 bridge back-load plate.stl, Gen4 bridge front-load body.stl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]
2023-03-20 Foxtrot into main (#2)
    * FOXTROT
    These are to be used with the V780 and optionally the V780 lenses
    * Update FOXTROT v20.step
    componentized
    * Reorganized .step, added README
    * Update README.md
    * tmp on foxtrot
    * tmp fix on foxtrot
    * Delete External_Battery_Only_with_Buck.png
    * Create External_Battery_Only_with_Buck.png
    * Update README.md
    * Update README.md
    * Update README.md
    * Create PVS-69 Gen3 FOXTROT.3mf
    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
    [+0 TIP.stl, +2 TIP_left.stl, +2 TIP_right.stl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]
2023-03-24 Fixed .stls for V780 housings
2023-03-24 updating .3mf files
    [PVS-69 Gen3 FOXTROT_V760 - No Lens Cap.3mf, PVS-69 Gen3 FOXTROT_V780 - No Lens Cap.3mf, PVS-69 Gen3 FOXTROT_V780_thicker display wall - No Lens.3mf]
2023-05-13 added CS Lens mount by Big Bronze Rim
    [CS_Focus_Insert.3mf, CS_Tapered_Retaining_Collar.3mf, PVS14_Focus_Ring_Outer.3mf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]
2023-08-21 Added CS Lens Mount .stls and moved some stuff around
    [CS_Focus_Insert.3mf, CS_Lens_Mount_Shroud.stl, CS_Tapered_Retaining_Collar.3mf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]
2023-08-21 Renamed cs mount stuff
    [CS_Ribbed_Spacer.3mf]
2024-11-21 Added Amazon link for M3x45mm bolts for Gen 4 bill of materials (#7)
